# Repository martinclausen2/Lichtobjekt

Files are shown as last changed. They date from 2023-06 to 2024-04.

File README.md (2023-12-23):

# Lichtobjekt

The "Lichtobjekt" projects allows to create portable lighting appliances.

## Features

- Two independent LED driver channels
  - Flicker free brightness control through current adjustment
- Integrated Li Ion battery charger
- Status LED to indicate power on, channel, standby, and charging status
- Brightness measurement to adjust brightness at power on
- IR remote control (receiver and sender)
  -	Option to network devices
- Single rotational encoder and switch needed to control
- Embedded terminal to control settings, clock, and alarms

## Technical Features
- ARM Cortex M3 based STM32L151 microcontroller
  - EEPROM for permanent storage of settings
- RC5 based communication (sender and receiver)
- Two TPS61165DBVT step-up LED driver with PWM adjustment of LED driving current up to 350mA
- High dynamic brightness measurement with low cost phototransistor SFH320
- Low power design
  - Shutdown for IR receiver and voltage measurement
  - MCU power down and frequency adjustment
  - Low power logic voltage regulation with MCP1703
- Integrated Li Ion charger based on BQ2057WSN
  - Battery temperature monitoring
  - Charging status
  - 2S cell configuration
- PCB prepared (not used in current software) for 
  - Acceleration sensor MMA8452
  - Pin headers for extension with additional I2C devices, LCD, or LED drivers
  - RTC RV3029-C2 - currently the MCU's internal RTC is utilized 
  - EEPROM from 24CXXX series with I2C connection - currently the MCU's internal EEPROM is utilized, the EEPROM can be populated if other STM32 MCU are to be used which do not contain a EEPROM

# Design description

## Hardware

### MCU
The STM32L1 series features for this application relevant features like a large number of timers, specific low power modes, and an embedded EEPROM.

The MCU can be programmed and debugged via SWD accessable through a custom pin header, that also exposes the serial port.

### LED Driver
To drive a sufficient number of LEDs for edge illumination without efficiency reducing current balancing resistors, a LED driver with a step-up topology was selected. A two cell battery increases the efficiency of the step-up LED driver.

### RC5 receiver and sender

A IR emitting diode is driven by a small MOSFET from the PWM output of a timer in the MCU to send RC5 commands.

To receive RC5 commands the output of the IR receiver is sampled at a rate of about 4.5kHz by the MCU. The power supply of the IR receiver is cut in standby mode to prevent the battery to be drained prematurely.

### Brightness Sensor

The ambient brightness is sensed via an in expensive a broadly available phototransistor SFA 320. To enhance the dynamic range, the MCU can switch the bias current between two different levels.
The precision is fully sufficient to adjust the brightness of the power LEDs at power on and dim the status LED in standby.

### Battery Charger

The battery charger follows example application of the BQ2057 charging controller. The input voltage should be 9 V to avoid excessive power dissipation in the charging current regulating power transistor.
In newer hardware revision could switch off the charger during overvoltage conditions - However, the implementation in software is currently pending.
The status output is read by the MCU, that controls the status LED accordingly.
A temperature sensor is used to stop the charging if an overtemperature condition of the battery is detected.

## Software

TBA

## Known Limitations
- Very low power modes of MCU cannot be used, since to polarity of the encoder switch is not suitable.
- The MCU does not switch the battery charger off, if the input voltage would lead to a thermal overload of the charging transistor.
The batch of pcb made is missing the required hardware prerequisites. The latest version contains the required circuits, but has not been manufactured yet.
The batch is also missing the MOSFET to shutdown the battery temperature and external voltage measurement. Due to the high leakage current of the charging transistor, the battery is drained with about 400µA also during power down.
- The ioc file currently targets the STM32L151 which is not available anymore. The setup can easily be changed to the STM32L151A.

# User Manual

The user interface is rather simplistic.

Turning the encoder increases or decreases the brightness.
The integrated push button is used to select functionality and change between on and off.
Detailed settings can be adjusted via the serial terminal.

Coming from standby a short button press switches the light on. A long button press activates the networked mode, where other compatible lighting appliances receive commands to follow on, off, and brightness settings.

When the appliance in on the short button press selects between the two individual LED strings and a mode where the brightness is modulated between the two channels.

When the button is pressed, the status led previews a for a short time the next selected functionality.

Standby can be reached via a long button pressed from power on mode.

| LED Color 	| Condition | Status | 
| :--- | :--- | :--- |
| red			| | standby  |
| white			| | power on |
| blue flashing | | charging |
| green flash	| while adjusting brightness | maximum brightness reached |
| red flash		| while adjusting brightness | minimum brightness reached |
| white flash	| pressing the button short | selected first LED channel  |
| red flash		| pressing the button short | selected second LED channel |
| pink flash	| pressing the button short | selected mood light mode	 |
| blue flash	| pressing the button long to power off | duration of flash corresponds to the charging status of the battery |
| green flash	| pressing the button very long | cancel button pressed |

The white flash is actually not visible, since the LED is already shining white.

# Configuration Manual

The serial port uses the following parameter 115200 Baud rate, data site 8, parity none, stop bits 1

The commands can be listed by sending the command 'help'.

## Available Commands

### Set Brightness

	bright [type] <-c channel_no> <-b brightness_value>

set brightness values

| Type | Decription |
| :--- | :--- |
| 0 | Brightness last used before lights were switched off. |
| 1 | Minimum brightness when switched on |
| 2 | Maximum brightness any time |
| 3 | Maximum brightness when an alarm is triggered |
| 4 | PWM offset for brightness |
| 5 | Current brightness |

### Get External Brightness

	getextbright

Get the external brightness from the phototransistor

### Infrared Remote Control

	remote <-a address> <-rm receiver mode> <-sm sender mode> <-sa send address> <-sd send data>

set infrared remote parameters

| Mode | Decription |
| :--- | :--- |
| 0 | Off |
| 1 | Alarm |
| 2 | Condional |
| 3 | All |

### Set Date and Time

	time [hour] [minute] [second]

set time of RTC

	date [2 digit year] [month] [day] [w] with w weekday

set date of RTC

	timestamp

get date and time from RTC

### Alarm

	alarmschedule [alarm no] <-w weekday> <-h hour> <-m minute>

set alarm schedule

	alarmsetting <-f time to fade-in light>

set alarm parameters
	
	alarm <-a 1 | 0> <-s alarm skip count>

trigger, reset, set alarm skip count

### Power and Battery

	power <-l 1 | 0>\r\n<-ub battery voltage> <-mub minimum battery voltage>\r\n<-up external power voltage> <-mup minimum external power voltage difference>

switch light, set min external power and battery voltage and calibration

Voltages are given in mV.

### Reset Settings

	reset

reset settings to factory defaults

### Status LED

	statusled [flash count]

flash status led

### Mood light

	fadelight <-f 1 | 0> time - <-t time> <-b brightness> <-mb maximum brightness>

switch and parameterize on mood light

### Version

	version

show STM32 software version

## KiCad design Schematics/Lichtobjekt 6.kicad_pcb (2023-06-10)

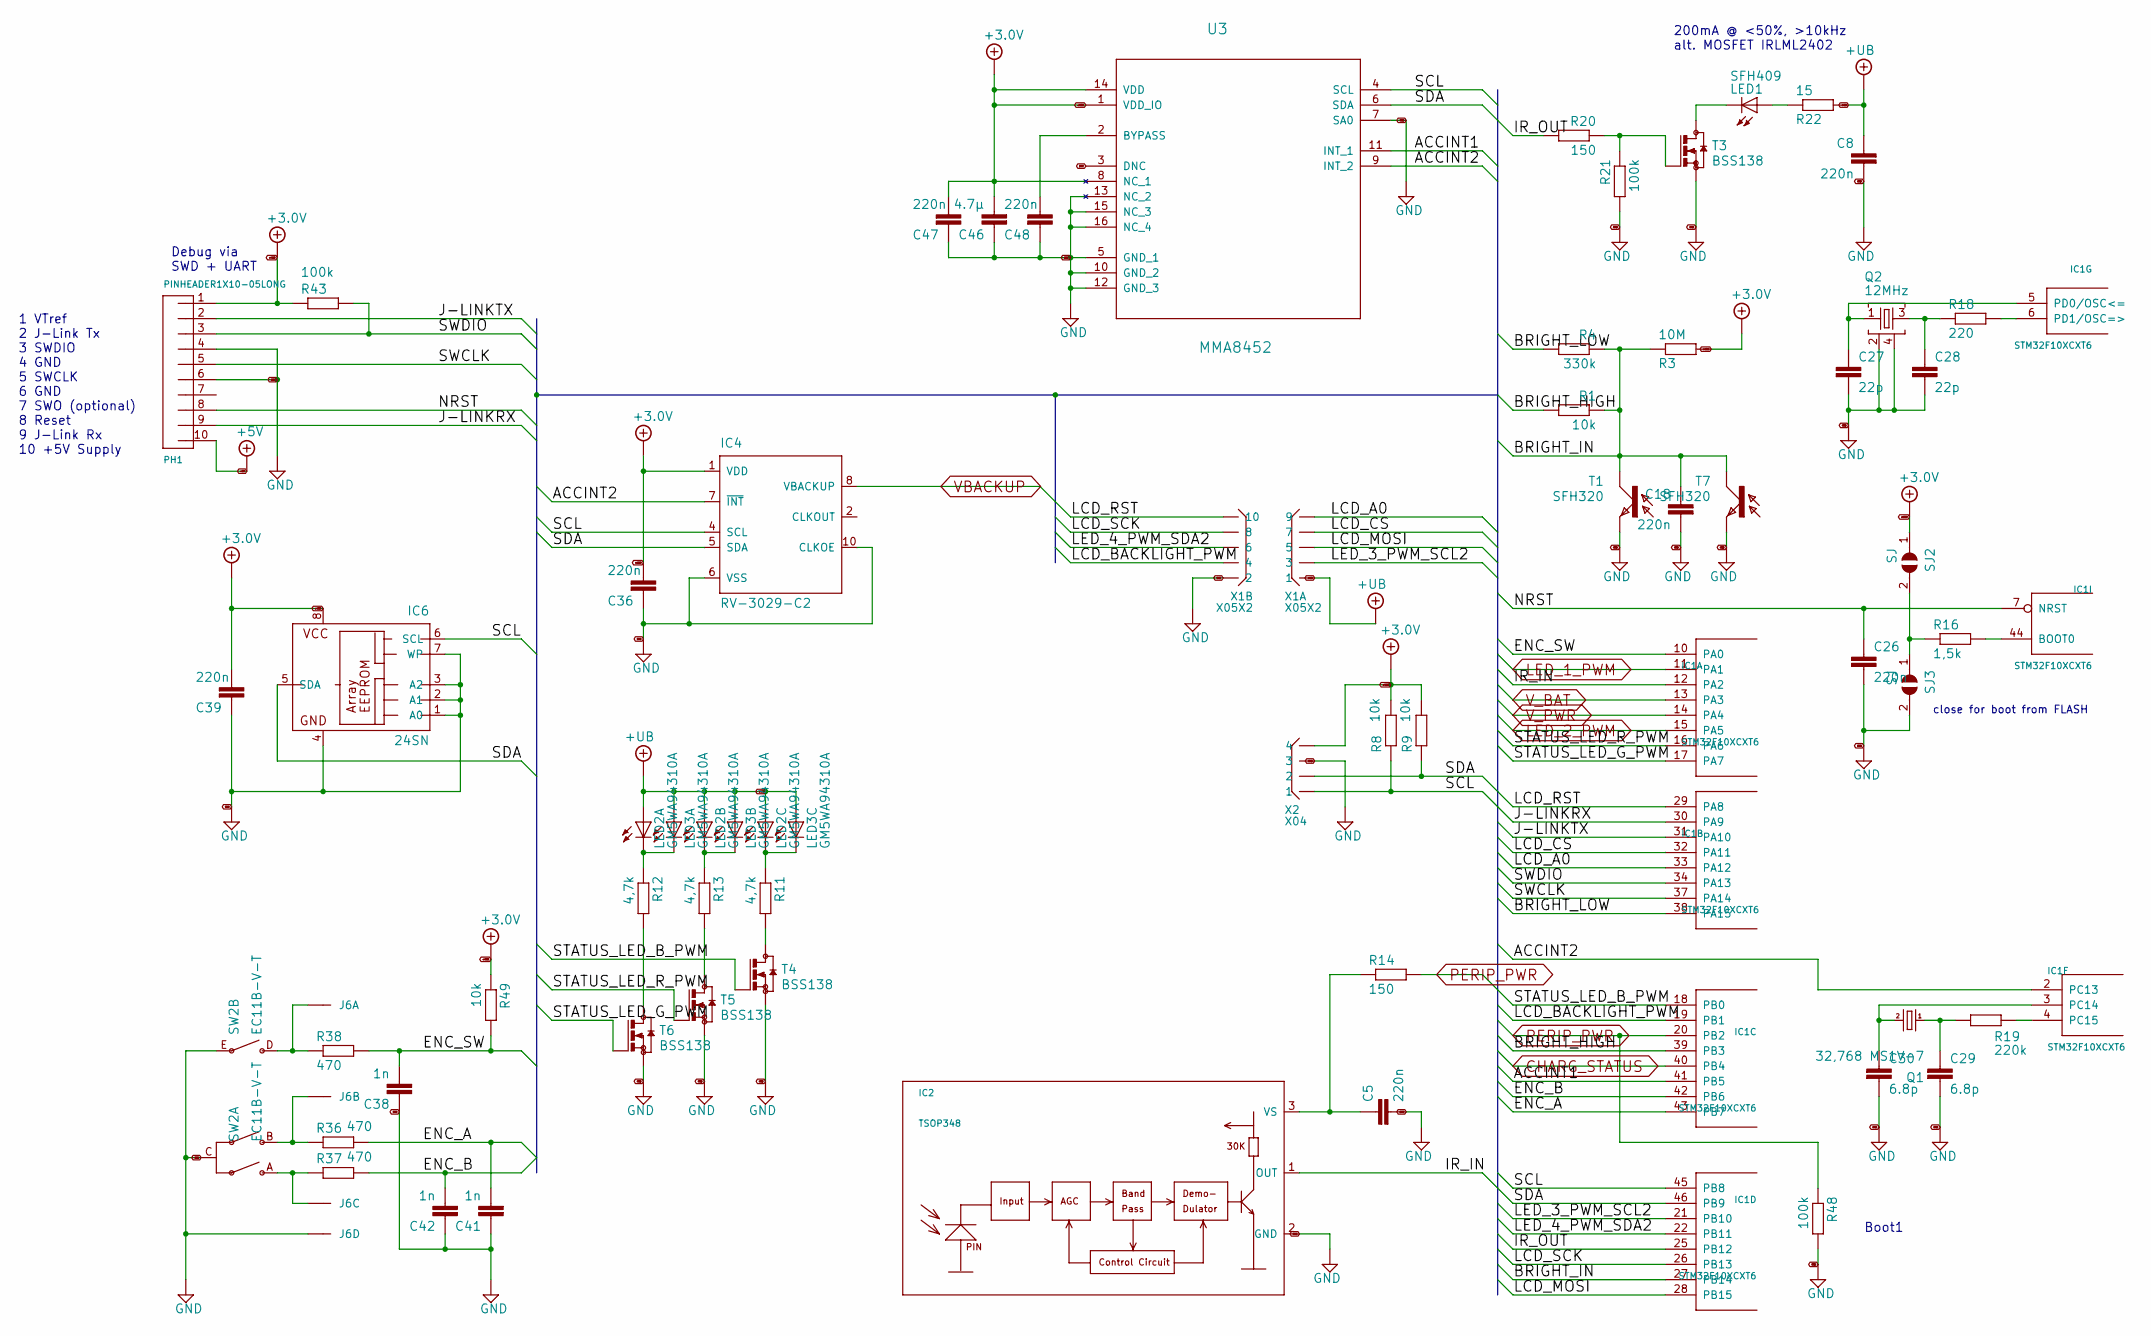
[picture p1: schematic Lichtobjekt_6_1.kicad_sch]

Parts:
C5, C8, C18, C26, C36, C39, C47, C48: 220n; C0603
C27, C28: 22p; C0603
C29, C30: 6.8p; C0603
C38, C41, C42: 1n; C0603
C46: 4.7µ; C0805
IC1: STM32F10XCXT6; TQFP48
IC2: TSOP348
IC4: RV-3029-C2; SON-10
IC6: 24SN; SO-08
J6: 22-?-0427-2041; 6410-04
LED1: SFH409; LED3MM
LED2, LED3: GM5WA94310A
PH1: PINHEADER1X10-05LONG; PINHEADER_005-1-10
Q1: 32,768 MS1V-7; MS1V-T1K
Q2: 12MHz; 3.4X2.7-4-PAD
R1, R8, R9, R49: 10k; R0805
R3: 10M; R0805
R4: 330k; R0805
R11, R12, R13: 4,7k; R0805
R14, R20: 150; R0805
R16: 1,5k; R0805
R18: 220; R0805
R19: 220k; R0805
R21, R43, R48: 100k; R0805
R22: 15; R1206
R36, R37, R38: 470; R0805
SJ2, SJ3: SJ
SW2: EC11B-V-T; EC11B-V
T1, T7: SFH320; LED_PLCC-2
T3, T4, T5, T6: BSS138; SOT23
U3: MMA8452; LGA16R50P3X5_300X300X100
X1: X05X2; X10N-IDC
X2: X04; X04N-SIL

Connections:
+5V: PH1.10; also elsewhere on the board
+UB: C8.1, LED2.1 (A), LED2.2 (A), LED2.3 (A), LED3.1 (A), LED3.2 (A), LED3.3 (A), R22.2, X1.1; also elsewhere on the board
+UB3: C36.1, C39.1, C46.2, C47.1, IC4.1 (VDD), IC6.8 (VCC), PH1.1, R3.2, R8.2, R9.2, R43.1, R49.1, SJ2.1, U3.1 (VDD_IO), U3.8 (NC_1), U3.14 (VDD), X2.4; also elsewhere on the board
/Lichtobjekt 6_1/ACCINT1: IC1.41 (PB5), U3.11 (INT_1)
/Lichtobjekt 6_1/ACCINT2: IC1.2 (PC13), IC4.7 (~INT), U3.9 (INT_2)
/Lichtobjekt 6_1/BRIGHT_HIGH: IC1.39 (PB3), R1.2
/Lichtobjekt 6_1/BRIGHT_IN: C18.1, IC1.27 (PB14), R1.1, R3.1, R4.1, T1.1 (C), T7.1 (C)
/Lichtobjekt 6_1/BRIGHT_LOW: IC1.38 (PA15), R4.2
/Lichtobjekt 6_1/ENC_A: C41.2, IC1.43 (PB7), R36.2
/Lichtobjekt 6_1/ENC_B: C42.2, IC1.42 (PB6), R37.2
/Lichtobjekt 6_1/ENC_SW: C38.2, IC1.10 (PA0), R38.2, R49.2
/Lichtobjekt 6_1/IR_IN: IC1.12 (PA2), IC2.1 (OUT)
/Lichtobjekt 6_1/IR_OUT: IC1.25 (PB12), R20.2
/Lichtobjekt 6_1/J-LINKRX: IC1.30 (PA9), PH1.9
/Lichtobjekt 6_1/J-LINKTX: IC1.31 (PA10), PH1.2
/Lichtobjekt 6_1/LCD_A0: IC1.33 (PA12), X1.9
/Lichtobjekt 6_1/LCD_BACKLIGHT_PWM: IC1.19 (PB1), X1.4
/Lichtobjekt 6_1/LCD_CS: IC1.32 (PA11), X1.7
/Lichtobjekt 6_1/LCD_MOSI: IC1.28 (PB15), X1.5
/Lichtobjekt 6_1/LCD_RST: IC1.29 (PA8), X1.10
/Lichtobjekt 6_1/LCD_SCK: IC1.26 (PB13), X1.8
/Lichtobjekt 6_1/LED_3_PWM_SCL2: IC1.21 (PB10), X1.3
/Lichtobjekt 6_1/LED_4_PWM_SDA2: IC1.22 (PB11), X1.6
/Lichtobjekt 6_1/NRST: C26.1, IC1.7 (NRST), PH1.8
/Lichtobjekt 6_1/SCL: IC1.45 (PB8), IC4.4 (SCL), IC6.6 (SCL), R8.1, U3.4 (SCL), X2.1
/Lichtobjekt 6_1/SDA: IC1.46 (PB9), IC4.5 (SDA), IC6.5 (SDA), R9.1, U3.6 (SDA), X2.2
/Lichtobjekt 6_1/STATUS_LED_B_PWM: IC1.18 (PB0), T4.1 (G)
/Lichtobjekt 6_1/STATUS_LED_G_PWM: IC1.17 (PA7), T6.1 (G)
/Lichtobjekt 6_1/STATUS_LED_R_PWM: IC1.16 (PA6), T5.1 (G)
/Lichtobjekt 6_1/SWCLK: IC1.37 (PA14), PH1.5
/Lichtobjekt 6_1/SWDIO: IC1.34 (PA13), PH1.3, R43.2
CHARG_STATUS: IC1.40 (PB4); also elsewhere on the board
DNC: U3.3 (DNC)
GND: C5.2, C8.2, C18.2, C26.2, C27.2, C28.2, C29.2, C30.2, C36.2, C38.1, C39.2, C41.1, C42.1, C46.1, C47.2, C48.2, IC2.2 (GND), IC4.6 (VSS), IC4.10 (CLKOE), IC6.1 (A0), IC6.2 (A1), IC6.3 (A2), IC6.4 (GND), IC6.7 (WP), J6.4, PH1.4, PH1.6, Q2.2, Q2.4, R21.2, R48.2, SJ3.2, SW2.C, SW2.E, T1.2 (E), T3.2 (S), T4.2 (S), T5.2 (S), T6.2 (S), T7.2 (E), U3.5 (GND_1), U3.7 (SA0), U3.10 (GND_2), U3.12 (GND_3), U3.13 (NC_2), U3.15 (NC_3), U3.16 (NC_4), X1.2, X2.3; also elsewhere on the board
LED_1_PWM: IC1.11 (PA1); also elsewhere on the board
LED_2_PWM: IC1.15 (PA5); also elsewhere on the board
unnamed: C5.1, IC2.3 (VS), R14.1
unnamed: C27.1, IC1.5 (PD0/OSC<=), Q2.1
unnamed: C28.1, Q2.3, R18.1
unnamed: C29.1, Q1.1, R19.1
unnamed: C30.1, IC1.3 (PC14), Q1.4 (2)
unnamed: C48.1, U3.2 (BYPASS)
unnamed: IC1.4 (PC15), R19.2
unnamed: IC1.6 (PD1/OSC=>), R18.2
unnamed: IC1.44 (BOOT0), R16.2
unnamed: J6.1, R38.1, SW2.D
unnamed: J6.2, R36.1, SW2.B
unnamed: J6.3, R37.1, SW2.A
unnamed: LED1.A, R22.1
unnamed: LED1.K (C), T3.3 (D)
unnamed: LED2.4 (C), LED3.4 (C), R13.1
unnamed: LED2.5 (C), LED3.5 (C), R12.1
unnamed: LED2.6 (C), LED3.6 (C), R11.1
unnamed: R11.2, T4.3 (D)
unnamed: R12.2, T6.3 (D)
unnamed: R13.2, T5.3 (D)
unnamed: R16.1, SJ2.2, SJ3.1
unnamed: R20.1, R21.1, T3.1 (G)
PERIP_PWR: IC1.20 (PB2), R14.2, R48.1; also elsewhere on the board
VBACKUP: IC4.8 (VBACKUP); also elsewhere on the board
V_BAT: IC1.13 (PA3); also elsewhere on the board

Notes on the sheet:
Debug via SWD + UART
200mA @ <50%, >10kHz alt. MOSFET IRLML2402
close for boot from FLASH
Boot1
1 VTref 2 J-Link Tx 3 SWDIO 4 GND 5 SWCLK 6 GND 7 SWO (optional) 8 Reset 9 J-Link Rx 10 +5V Supply

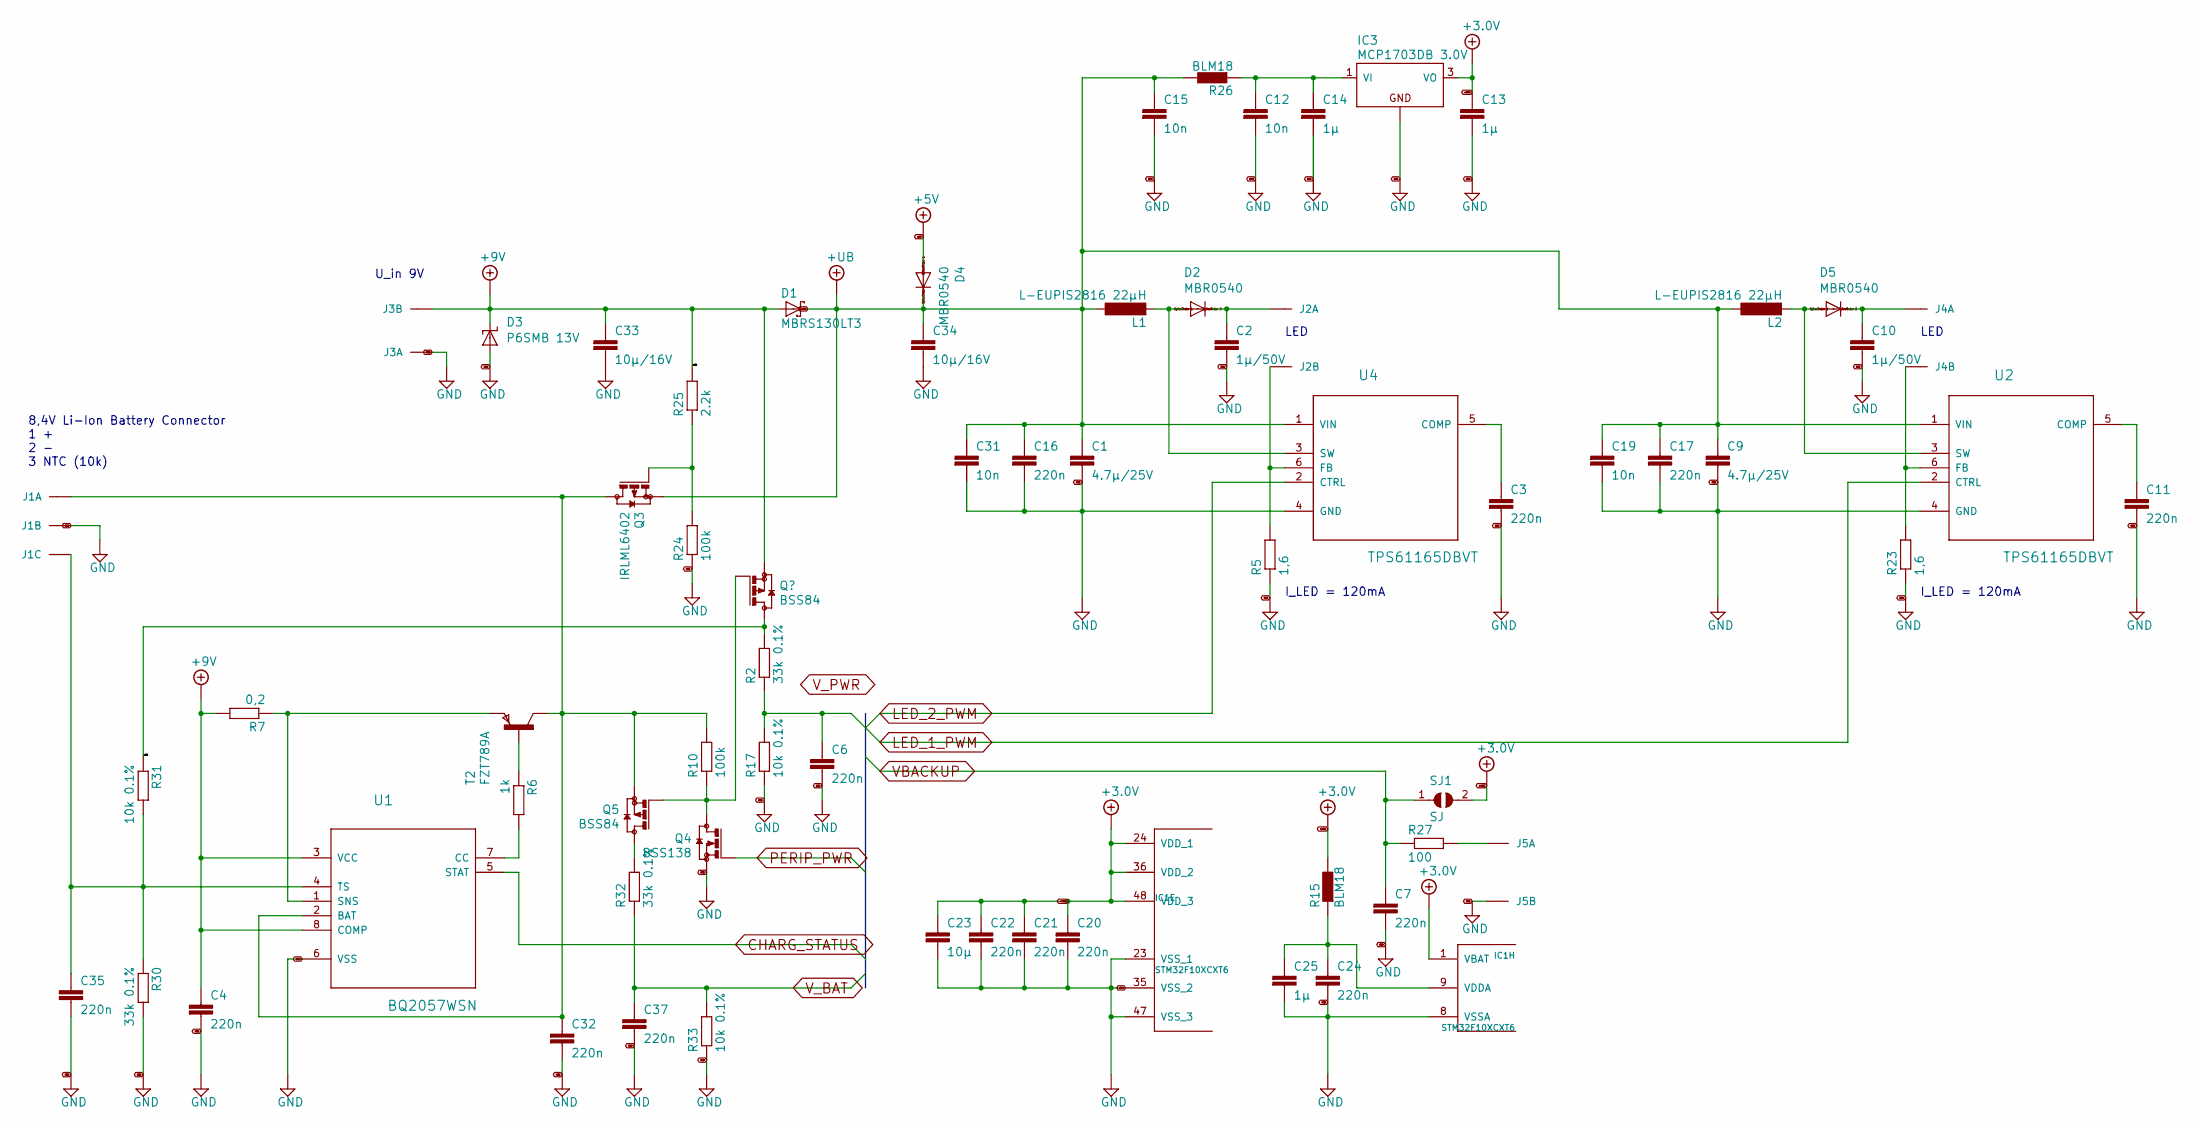
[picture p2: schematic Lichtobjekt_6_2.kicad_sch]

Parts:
C1, C9: 4.7µ/25V; C0805
C2, C10: 1µ/50V; C0805
C3, C4, C6, C7, C11, C16, C17, C20, C21, C22, C24, C32, C35, C37: 220n; C0603
C12, C15, C19, C31: 10n; C0603
C13, C14, C25: 1µ; C0805
C23: 10µ; C0805
C33, C34: 10µ/16V; C1210
D1: MBRS130LT3; SMB
D2, D4, D5: MBR0540; SOD123
D3: P6SMB 13V; SMBJ
IC1: STM32F10XCXT6; TQFP48
IC3: MCP1703DB 3.0V; SOT223
J1: 22-27-2031-03; 6410-03
J2, J3, J4, J5: 22-?-0227-2021; 6410-02
L1, L2: L-EUPIS2816 22µH; PIS28XX
Q3: IRLML6402; SOT23
Q4: BSS138; SOT23
Q5: BSS84; SOT23
R2, R30, R32: 33k 0.1%; R0805
R5, R23: 1,6; R1206
R6: 1k; R0805
R7: 0,2; R1206
R10, R24: 100k; R0805
R15, R26: BLM18; R0805
R17, R31, R33: 10k 0.1%; R0805
R25: 2.2k; R0805
R27: 100; R0805
SJ1: SJ
T2: FZT789A; SOT223
U1: BQ2057WSN; SOIC127P600X175-8N
U2, U4: TPS61165DBVT; SOT95P280X145-6N

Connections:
+5V: D4.A; also elsewhere on the board
+9V: C4.1, C33.1, D1.A, D3.C, J3.2, R2.2, R7.2, R25.2, R31.1, U1.3 (VCC), U1.8 (COMP)
+UB: C1.1, C9.1, C15.1, C16.1, C17.1, C19.1, C31.1, C34.1, D1.C, D4.C, L1.2 (1), L2.2 (1), Q3.2 (S), R26.2, U2.1 (VIN), U4.1 (VIN); also elsewhere on the board
+UB3: C13.1, C20.1, C21.1, C22.1, C23.1, IC1.1 (VBAT), IC1.24 (VDD_1), IC1.36 (VDD_2), IC1.48 (VDD_3), IC3.3 (VO), R15.2, SJ1.2; also elsewhere on the board
CHARG_STATUS: U1.5 (STAT); also elsewhere on the board
GND: C1.2, C2.2, C3.2, C4.2, C6.2, C7.2, C9.2, C10.2, C11.2, C12.2, C13.2, C14.2, C15.2, C16.2, C17.2, C19.2, C20.2, C21.2, C22.2, C23.2, C24.2, C25.2, C31.2, C32.2, C33.2, C34.2, C35.2, C37.2, D3.A, IC1.8 (VSSA), IC1.23 (VSS_1), IC1.35 (VSS_2), IC1.47 (VSS_3), IC3.2 (GND), IC3.4 (GND), J1.2, J3.1, J5.2, Q4.2 (S), R5.1, R17.1, R23.1, R24.1, R30.2, R33.1, U1.6 (VSS), U2.4 (GND), U4.4 (GND); also elsewhere on the board
LED_1_PWM: U2.2 (CTRL); also elsewhere on the board
LED_2_PWM: U4.2 (CTRL); also elsewhere on the board
unnamed: C2.1, D2.C, J2.1
unnamed: C3.1, U4.5 (COMP)
unnamed: C10.1, D5.C, J4.1
unnamed: C11.1, U2.5 (COMP)
unnamed: C12.1, C14.1, IC3.1 (VI), R26.1
unnamed: C24.1, C25.1, IC1.9 (VDDA), R15.1
unnamed: C32.1, J1.1, Q3.3 (D), Q5.2 (S), R10.2, T2.2 (C), T2.4 (C), U1.2 (BAT)
unnamed: C35.1, J1.3, R30.1, R31.2, U1.4 (TS)
unnamed: D2.A, L1.1 (2), U4.3 (SW)
unnamed: D5.A, L2.1 (2), U2.3 (SW)
unnamed: J2.2, R5.2, U4.6 (FB)
unnamed: J4.2, R23.2, U2.6 (FB)
unnamed: J5.1, R27.2
unnamed: Q3.1 (G), R24.2, R25.1
unnamed: Q4.3 (D), Q5.1 (G), R10.1
unnamed: Q5.3 (D), R32.2
unnamed: R6.1, T2.1 (B)
unnamed: R6.2, U1.7 (CC)
unnamed: R7.1, T2.3 (E), U1.1 (SNS)
PERIP_PWR: Q4.1 (G); also elsewhere on the board
VBACKUP: C7.1, R27.1, SJ1.1; also elsewhere on the board
V_BAT: C37.1, R32.1, R33.2; also elsewhere on the board

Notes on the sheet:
I_LED = 120mA
LED
U_in 9V
8,4V Li-Ion Battery Connector 1 + 2 - 3 NTC (10k)

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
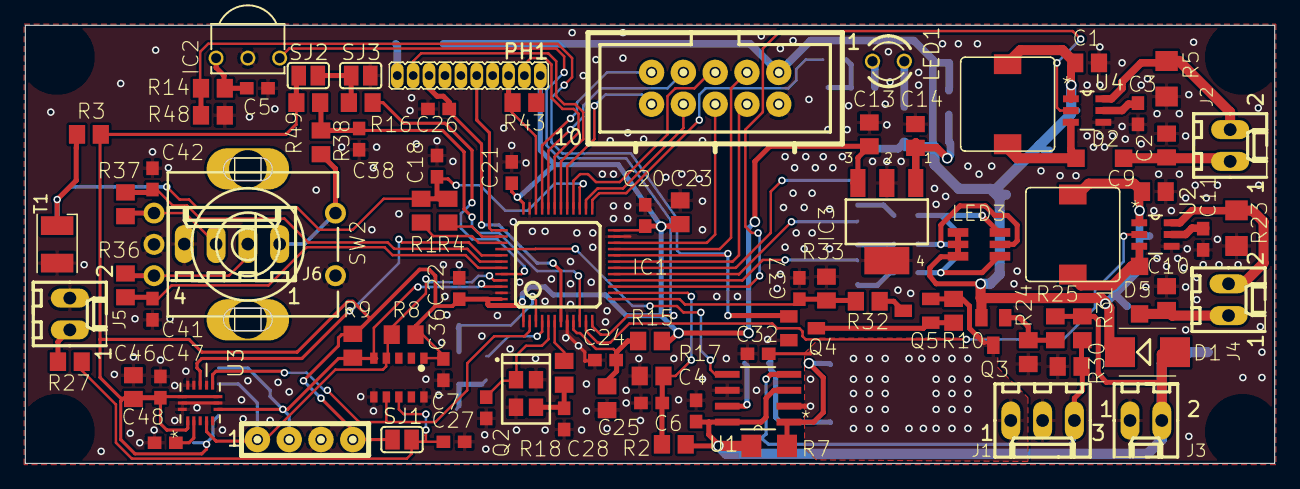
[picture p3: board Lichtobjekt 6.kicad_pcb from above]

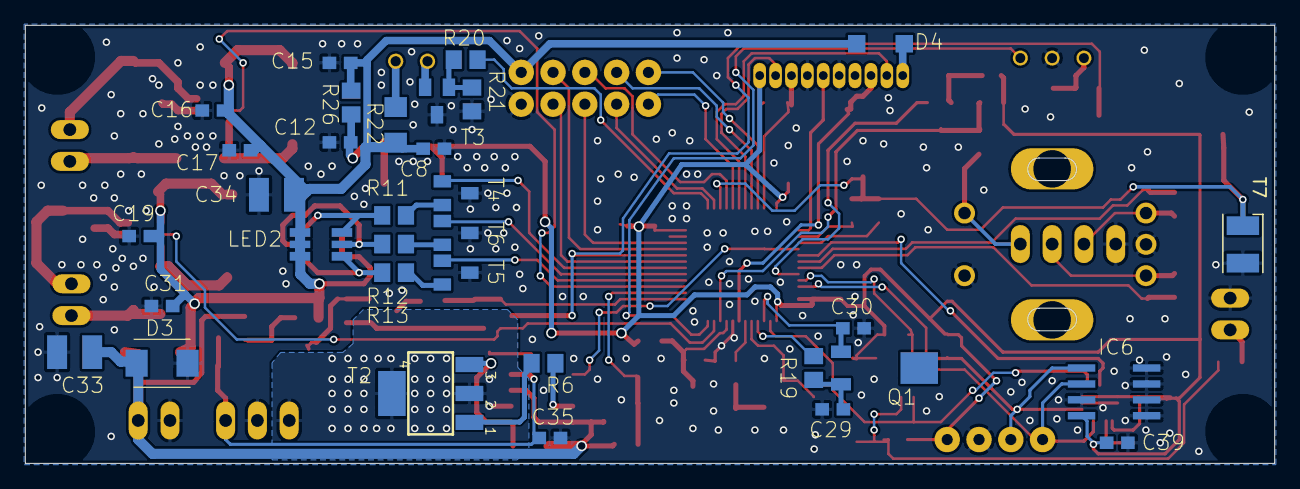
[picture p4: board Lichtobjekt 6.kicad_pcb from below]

Board: 2 copper layers, 99.8 x 35.0 mm, 125 parts (33 on the bottom side), 81 nets.

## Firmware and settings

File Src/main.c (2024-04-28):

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
/* Includes ------------------------------------------------------------------*/
#include "main.h"

ADC_HandleTypeDef hadc;
DMA_HandleTypeDef hdma_adc;

CRC_HandleTypeDef hcrc;

RTC_HandleTypeDef hrtc;

TIM_HandleTypeDef htim2;
TIM_HandleTypeDef htim3;
TIM_HandleTypeDef htim4;
TIM_HandleTypeDef htim6;
TIM_HandleTypeDef htim10;
TIM_HandleTypeDef htim11;

UART_HandleTypeDef huart1;
DMA_HandleTypeDef hdma_usart1_rx;
DMA_HandleTypeDef hdma_usart1_tx;

/* USER CODE BEGIN PV */
bool volatile TimerFlag;
/* USER CODE END PV */

void SystemClock_Config(void);
static void MX_GPIO_Init(void);
static void MX_DMA_Init(void);
static void MX_RTC_Init(void);
static void MX_TIM2_Init(void);
static void MX_TIM3_Init(void);
static void MX_TIM4_Init(void);
static void MX_TIM10_Init(void);
static void MX_ADC_Init(void);
static void MX_USART1_UART_Init(void);
static void MX_TIM6_Init(void);
static void MX_TIM11_Init(void);
static void MX_CRC_Init(void);
/* USER CODE BEGIN PFP */
#define PUTCHAR_PROTOTYPE int __io_putchar(int ch)
/* USER CODE END PFP */

/**
  * @brief  The application entry point.
  * @retval int
  */
int main(void)
{

  /* MCU Configuration--------------------------------------------------------*/

  /* Reset of all peripherals, Initializes the Flash interface and the Systick. */
  HAL_Init();

  /* Configure the system clock */
  SystemClock_Config();

  /* Initialize all configured peripherals */
  MX_GPIO_Init();
  MX_DMA_Init();
  MX_RTC_Init();
  MX_TIM2_Init();
  MX_TIM3_Init();
  MX_TIM4_Init();
  MX_TIM10_Init();
  MX_ADC_Init();
  MX_USART1_UART_Init();
  MX_TIM6_Init();
  MX_TIM11_Init();
  MX_CRC_Init();
  /* USER CODE BEGIN 2 */
  	// DMA: UART, DAC
  	// ADC: external brightness, voltages
    // I2C1: acceleration sensor (planned)
    // SPI2: display (planned)
  	// TIM2: LED PWM
  	// TIM3: status LED PWM
    // TIM4: rotational encoder
	// TIM6: RC5 decoder timing
    // TIM9: alternative RC5 decoder (planned)
    // TIM10: RC5 sender
    // TIM11: main control loop
    // USART1: terminal
    // CRC: EEPROM change check

	//load RAM values from EEPROM
	SettingsInit(&hcrc);

	Init_Terminal(&huart1);
	SettingsCommands_Init();
	Rtc_Init();
	PWM_Init(&htim2);
	Status_LED_Init(&htim3);
	Encoder_Init(&htim4);
	Init_ExtBrightness(&hadc);
	Init_FadeLight();
	RC5_Init(&htim6, &htim10);

	/*##-1- Start the TIM Base generation in interrupt mode ####################*/
	pTIM_CallbackTypeDef pMainTimerCallback = *MainTimerCallback;
	HAL_TIM_RegisterCallback(&htim11, HAL_TIM_PERIOD_ELAPSED_CB_ID, pMainTimerCallback);
	HAL_TIM_Base_Start_IT(&htim11); //main control loop

	SwAllLightOn();
  /* USER CODE END 2 */

  /* Infinite loop */
  /* USER CODE BEGIN WHILE */
	while (1)
	{
		if(TimerFlag)
		{
			TimerFlag=0;
			Keys(!HAL_GPIO_ReadPin(ENC_SW_GPIO_Port, ENC_SW_Pin));
			Encoder();
			MainMenu();
			Sample_ExtBrightness();
			LEDOptions();
		}
		Execute_Terminal();
		HAL_PWR_EnterSLEEPMode(PWR_MAINREGULATOR_ON, PWR_SLEEPENTRY_WFI);
    /* USER CODE END WHILE */

    /* USER CODE BEGIN 3 */
	}
  /* USER CODE END 3 */
}

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
/* USER CODE BEGIN 4 */

/*
 * @brief  Period elapsed callback in non blocking mode
 * @param  htim: TIM handle
 * @retval None
 */
void MainTimerCallback(TIM_HandleTypeDef *htim)
{
	//set flag, should be set at a frequency of 100Hz
	TimerFlag = true;
}

/* USER CODE END 4 */
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


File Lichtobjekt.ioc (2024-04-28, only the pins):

Mcu.UserName=STM32L151CBTx
PA0-WKUP1.GPIO_Label=ENC_SW
PA0-WKUP1.Signal=GPXTI0
PA1.GPIO_Label=LED_2_PWM
PA1.Signal=S_TIM2_CH2
PA10.GPIO_Label=J_LinkTX
PA10.Signal=USART1_RX
PA11.Signal=GPIO_Analog
PA12.Signal=GPIO_Analog
PA13.GPIO_Label=SWDIO
PA13.Signal=SYS_JTMS-SWDIO
PA14.GPIO_Label=SWCLK
PA14.Signal=SYS_JTCK-SWCLK
PA15.GPIO_Label=BRIGHT_LOW
PA15.Signal=GPIO_Output
PA2.GPIO_Label=IR_IN
PA2.Signal=GPIO_Input
PA3.GPIO_Label=U Bat
PA3.Signal=ADC_IN3
PA4.GPIO_Label=U Pwr
PA4.Signal=ADC_IN4
PA5.GPIO_Label=LED_1_PWM
PA5.Signal=S_TIM2_CH1_ETR
PA6.GPIO_Label=STATUS_LED_R_PWM
PA6.Signal=S_TIM3_CH1
PA7.GPIO_Label=STATUS_LED_G_PWM
PA7.Signal=S_TIM3_CH2
PA8.Signal=GPIO_Analog
PA9.GPIO_Label=J-LinkRX
PA9.Signal=USART1_TX
PB0.GPIO_Label=STATUS_LED_B_PWM
PB0.Signal=S_TIM3_CH3
PB1.Signal=GPIO_Analog
PB10.Signal=GPIO_Analog
PB11.Signal=GPIO_Analog
PB12.GPIO_Label=IR_OUT
PB12.Signal=S_TIM10_CH1
PB13.Signal=GPIO_Analog
PB14.GPIO_Label=BRIGHT_IN
PB14.Signal=ADC_IN20
PB15.Signal=GPIO_Analog
PB2.GPIO_Label=PERIP_PWR
PB2.Signal=GPIO_Output
PB3.GPIO_Label=BRIGHT_HIGH
PB3.Signal=GPIO_Output
PB4.GPIO_Label=Charging_Status
PB4.Signal=GPIO_Input
PB5.Signal=GPIO_Analog
PB6.GPIO_Label=ENC_B
PB6.Signal=S_TIM4_CH1
PB7.GPIO_Label=ENC_A
PB7.Signal=S_TIM4_CH2
PB8.Signal=GPIO_Analog
PB9.Signal=GPIO_Analog
PC13-WKUP2.Signal=GPIO_Analog
PC14-OSC32_IN.Signal=RCC_OSC32_IN
PC15-OSC32_OUT.Signal=RCC_OSC32_OUT

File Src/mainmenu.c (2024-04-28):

/*
 * mainmenu.c
 *
 *  Created on: Dec 22, 2019
 *      Author: Martin
 */

#include "mainmenu.h"

extern ADC_HandleTypeDef hadc;

bool awaitBatStandby = false;

void PrepareBatStandby() {
	SwAllLightOff();
	awaitBatStandby = true;
}

void EnterBatStandby()
{
	int uDelta = uBat - GLOBAL_settings_ptr->min_uBat;
	if (uDelta >0)
	{
		LEDSetColor(LEDBlue);
		HAL_Delay(uDelta*4);
	}
	LEDOff();
	HAL_Delay(10);
	//prepare for stopmode
	HAL_NVIC_DisableIRQ(TIM6_IRQn);
	HAL_NVIC_DisableIRQ(TIM11_IRQn);
	PhotoGain_t PhotoGain = {0};
	AdjustGain(PhotoGain);
	HAL_ADC_Stop_DMA(&hadc);
	//HAL_ADC_DeInit(); TODO add also init

	HAL_GPIO_WritePin(PERIP_PWR_GPIO_Port, PERIP_PWR_Pin, GPIO_PIN_RESET);
	//HAL_PWR_EnableWakeUpPin(PWR_WAKEUP_PIN1); not possible since polarity of switch is wrong (switch must pull up instead of down) otherwise standby entry at high level is directly recognized as wake up signal;
	HAL_SuspendTick();

	//enter stop mode
	HAL_PWR_EnterSTOPMode(PWR_LOWPOWERREGULATOR_ON, PWR_SLEEPENTRY_WFI);

	//restore operation
	SystemClock_Config();
	HAL_ResumeTick();
	HAL_GPIO_WritePin(PERIP_PWR_GPIO_Port, PERIP_PWR_Pin, GPIO_PIN_SET);
	LEDSetupStandby();
	Sample_ExtBrightness_now();
	HAL_NVIC_EnableIRQ(TIM11_IRQn);
	HAL_NVIC_EnableIRQ(TIM6_IRQn);
	SwAllLightOn();		//always start with on, to prevent falling directly into stop mode again when on battery
}

void MainMenu()
{
	static unsigned char actionCounter = 0xFF;

	PWM_StepDim();			// do next dimming step

	++actionCounter;

	// check keys here since we can have only new input if timer flag was set by the keys interrupt program
	// Select key is pressed, show preview of action
	// need to check each time to generate single events directly from KeyPressDuration counter
	if (1 == KeyState)
	{
		if (1 == KeyPressDuration)
			if (LightOn)
			{
				// Toggle focus
				LEDSetColorTemp(LEDWhite + PreviewToggelFocus());
			}
			else
			{
				// Switch on
				LEDOn();
			}
		else if (KeyPressShort == KeyPressDuration)
			if (LightOn)
			{
				LEDSetupStandby();
			}
			else
			{
				// Switch All On
				LEDOn();
			}
		else if (KeyPressLong == KeyPressDuration)
		{
			LEDCancel();
		}
	}

	switch (actionCounter)
	{
	case 0:
		DecodeRemote();
		// Flash LED if charging
		if (HAL_GPIO_ReadPin(Charging_Status_GPIO_Port, Charging_Status_Pin))
		{
			limit = charging;
			LEDSetupLimit();
		}
		// complete shutdown, if battery drained and external power is not available
		else if ((uBat < GLOBAL_settings_ptr->min_uBat) & ((uPwr + GLOBAL_settings_ptr->min_uPwr) < uBat))
		{
			PrepareBatStandby();
		}
		// if in standby and external power is removed, change to bat standby
		else if (!LightOn & (uPwr < (uBat + GLOBAL_settings_ptr->min_uPwr)))
		{
			PrepareBatStandby();
		}

		if (awaitBatStandby & (0==PWM_StepDimSteps()))
		{
			awaitBatStandby = false;
			EnterBatStandby();
		}
		break;
	case 1:
		CheckAlarm();
		LEDLimit();
		if ((FocusChannel == FadeLightChannel) & LightOn)
		{
			FadeLight();
		}
		else
		{
			ResetFadeLight();
		}
		if (LightOn)
		{
			StoreBrightness();	// store brightness if required
		}
		else
		{
			if (!KeyState)	//protect preview from being overwritten
			{
				LEDStandby();	//dim standby led according to external brightness
			}
			WriteTimer=0;
		}
		break;
	case 2:
		// A Key was released after pressed if OldKeyState = 1 and Keystate = 0
		// OldKeyState = 0 must be set by receiving program after decoding as a flag
		if ((1 == OldKeyState) && (0 == KeyState))
		{
			OldKeyState=0;		//Ack any key anyway
			if (KeyPressShort > KeyPressDuration)
			{
				if (LightOn)
				{
					ToggleFocus();
					LEDOn();
				}
				else
				{
					SendRC5(RC5Addr_com, RC5Cmd_On, ComModeAll, RC5Cmd_Repeats);
					SwAllLightOn();
				}
			}
			else if (KeyPressLong > KeyPressDuration)
			{
				AlarmEnd();
				ResetFadeLight();
				if (LightOn)
				{
					SendRC5(RC5Addr_com, RC5Cmd_Off, ComModeAll, RC5Cmd_Repeats);
					SwAllLightOff();
				}
				else
				{
					if (ComModeConditional<=SenderMode)		//reset to eeprom value in swalllightoff()
					{
						SenderMode=ComModeAll;
					}
					SendRC5(RC5Addr_com, RC5Cmd_On, ComModeAll, RC5Cmd_Repeats);
					SwAllLightOn();
				}
			}
			else
			{
				//Restore status led after preview
				if (LightOn)
					LEDOn();
				else
					LEDSetupStandby();
			}
		}
		break;
	case 3:
		// A Rotation occurred if EncoderSteps!= 0
		// EncoderSteps = 0 must be set by receiving program after decoding
		if (EncoderSteps)
		{
			if (LightOn)
			{
				PWM_SetupDim(FocusChannel, Brightness_steps, EncoderSteps, 0);
				EncoderSteps = 0;								//ack any steps
				LEDSetupLimit();
				WriteTimer=WriteTime;
				if ((RC5Addr_first + FocusChannel) < RC5Addr_com)
				{
					SendRC5(RC5Addr_first+FocusChannel, Brightness[FocusChannel], ComModeAll, RC5Value_Repeats);
				}
			}
		}
		actionCounter=0xFF;	//last time slot, do reset counter with increment to 0
		break;
	}
}

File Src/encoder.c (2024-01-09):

/*
 * encoder.c
 *
 *  Created on: 23.12.2019
 *      Author: Martin
 */

#include "encoder.h"

volatile int EncoderSteps;

TIM_HandleTypeDef *htim_encoder;						//handle to address timer

void Encoder_Init(TIM_HandleTypeDef *handle_tim)
{
	htim_encoder = handle_tim;
	HAL_TIM_Encoder_Start(htim_encoder, TIM_CHANNEL_ALL);
}

void Encoder()
{
	static unsigned short OldCounter;
	static short Acceleration;
	static unsigned short Decay;
	unsigned short Counter = htim_encoder->Instance->CNT;
	short DeltaCounter;

	DeltaCounter = Counter - OldCounter;
	//handle warp around
	if (DeltaCounter > MaxChange)
	{
		// counter underflow
		DeltaCounter -= MaxCounter;
	}
	else if (DeltaCounter < -MaxChange)
	{
		// counter overflow
		DeltaCounter += MaxCounter;
	}

	//Measure the number of steps, introduce acceleration
	if (DeltaCounter != 0)
		{
		EncoderSteps += DeltaCounter;
		EncoderSteps += DeltaCounter * Acceleration / AccelerationScale;
		++Acceleration;
		}
	else if (Decay > 0)
		{
		--Decay;
		}
	else
		{
		Decay=startDecay;
		if (Acceleration)
			{
			--Acceleration;			//no new step, decrease acceleration
			}
		}

	OldCounter = Counter;
}

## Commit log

2018-05-06 added schematics
    [Lichtobjekt.brd, Lichtobjekt.sch]
2021-03-28 added updated schematics and pin out file
    [Lichtobjekt 6.kicad_pcb, Lichtobjekt 6.sch, Lichtobjekt.brd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]
2021-06-05 version of PCB produced first version to show basic functionality incl. remote and serial monitor output
    [Lichtobjekt 6.kicad_pcb, Lichtobjekt_6_1.sch, Lichtobjekt_6_2.sch]
2021-06-05 adjust configuration tim3 fix status led
    [Lichtobjekt.ioc, main.c, mainmenu.c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]
2021-06-05 fix warnings change MCU to model with more memory C6 => CB suffix
    [Lichtobjekt.ioc]
2022-12-28 added missing init for sender mode added persistence for settings and last brightness measured via sensor code compiles is untested with respect to persistence and brightness measurement. added missi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
    [Lichtobjekt.ioc, RC5.c, encoder.c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]
2023-06-08 removed unused pin configuration adjusted MSI frequency and PWM range to maintain min. 5kHz PWM frequency with MSI osc disabled RC5 and CRC, both currently broken started to work on voltage measureme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
    [Lichtobjekt.ioc, RC5.c, extbrightness.c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]
2023-06-10 minor code cleanup fix missing array size added DMA for ADC run core at 8 to keep up with interrupts during RC5 encoding and better PWM resolution replace wake up pin with ext interrupted due to wron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
    known issues: RC5 encoder not working, early weak up form low power standby, missing low power stand by for battery operation
    [Lichtobjekt.ioc, RC5.c, extbrightness.c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]
2023-06-10 added battery deep power down added measures to minimize power consumption in stop mode
    [Lichtobjekt 6.kicad_pcb]
2023-06-11 added P-MOSFET to switch voltage and temp measurements to avoid battery draining due to leak current via charging pnp transistor and control charging of battery
    [Lichtobjekt 6.kicad_sch, Lichtobjekt_6_1.kicad_sch, Lichtobjekt_6_2.kicad_sch]
2023-06-11 dynamically switch to 16 MHz during RC5 encoding, at 8 MHz the timing was incorrect
2023-07-16 fix crc by replacing old sysmem.c fix comments and terminal output texts
    [Lichtobjekt.ioc, mainmenu.c, settigscommands.c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]
2023-10-07 apply changes and fixes to skip alarm and terminal
    [mainmenu.c, rtc.c]
2023-10-07 fix fadelight and alarmskipcounter
    [Lichtobjekt.ioc, settigscommands.c]
2023-10-10 fix statusled fix error handling, remove dely in UART code for terminal add version command
    [settigscommands.c, status_LED.c]
2023-10-11 fix remote control from other lamp switch off time of standby led in battery mode indicates battery voltage
    [RC5.c, mainmenu.c]
2023-10-11 fix battery indicator
2023-11-01 fix alarm end when command send via terminal
    [settigscommands.c]
2023-11-05 minor fix in terminal
    [settigscommands.c]
2023-12-23 added README.md minor fix update CubeMX version
    [Lichtobjekt.ioc, settigscommands.c]
2023-12-25 fixed encoder
2024-01-09 remove dead code and fix brightness settings
    [encoder.c, setbrightness.c]
2024-01-24 fix fadelight adjust encoder acceleration
2024-04-28 update CUBE MX version fix RC5 sender: duty cycle and toggle bit
    [Lichtobjekt.ioc, RC5.c, main.c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]

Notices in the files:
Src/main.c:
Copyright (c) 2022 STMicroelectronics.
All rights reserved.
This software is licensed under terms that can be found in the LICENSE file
